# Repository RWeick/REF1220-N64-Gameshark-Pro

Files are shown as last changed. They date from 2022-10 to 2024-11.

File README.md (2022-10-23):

# REF1220-N64-Gameshark-Pro
An optimized PCB for the N64 Gameshark Pro as well as the full schematic. This is the second revision of the N64 Gameshark which was intended to support a smart card method of updating codes and adding features. The Gameshark Pro bin file should be programmed with the low bytes to the bottom SST and the high bytes to the top SST. It's worth noting that no smart cards were ever released for use with this Gameshark.

PCB Thickness: 1.2 mm

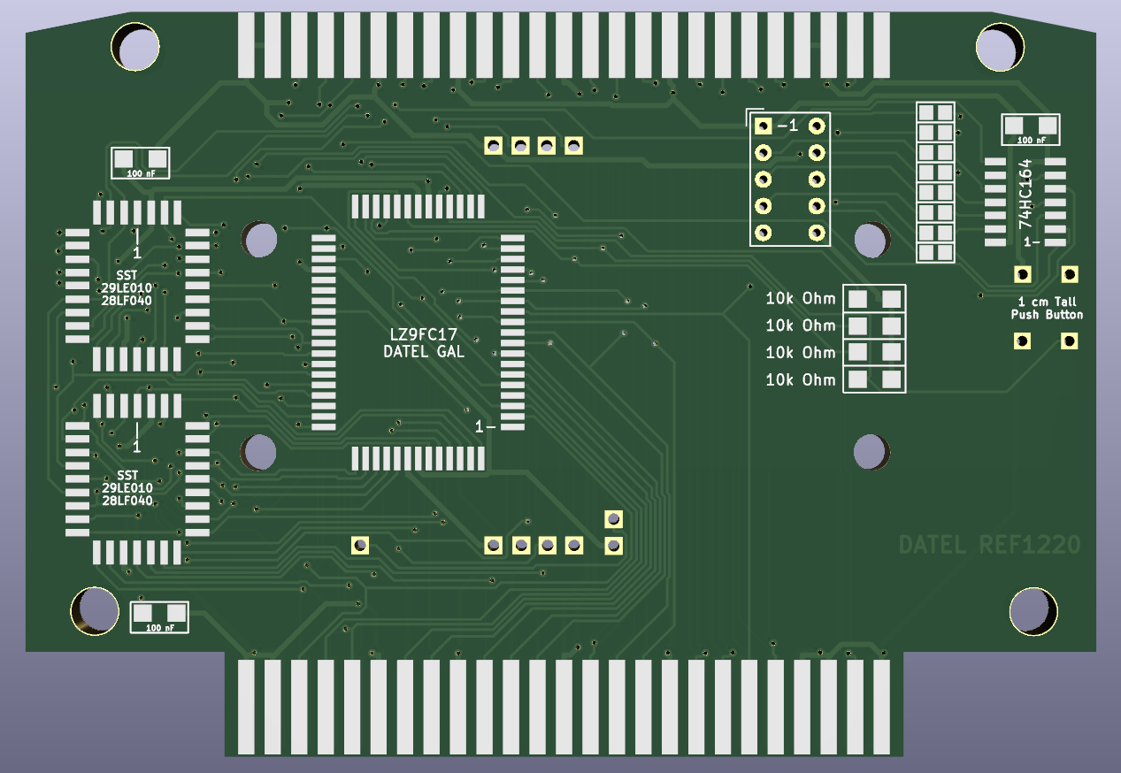
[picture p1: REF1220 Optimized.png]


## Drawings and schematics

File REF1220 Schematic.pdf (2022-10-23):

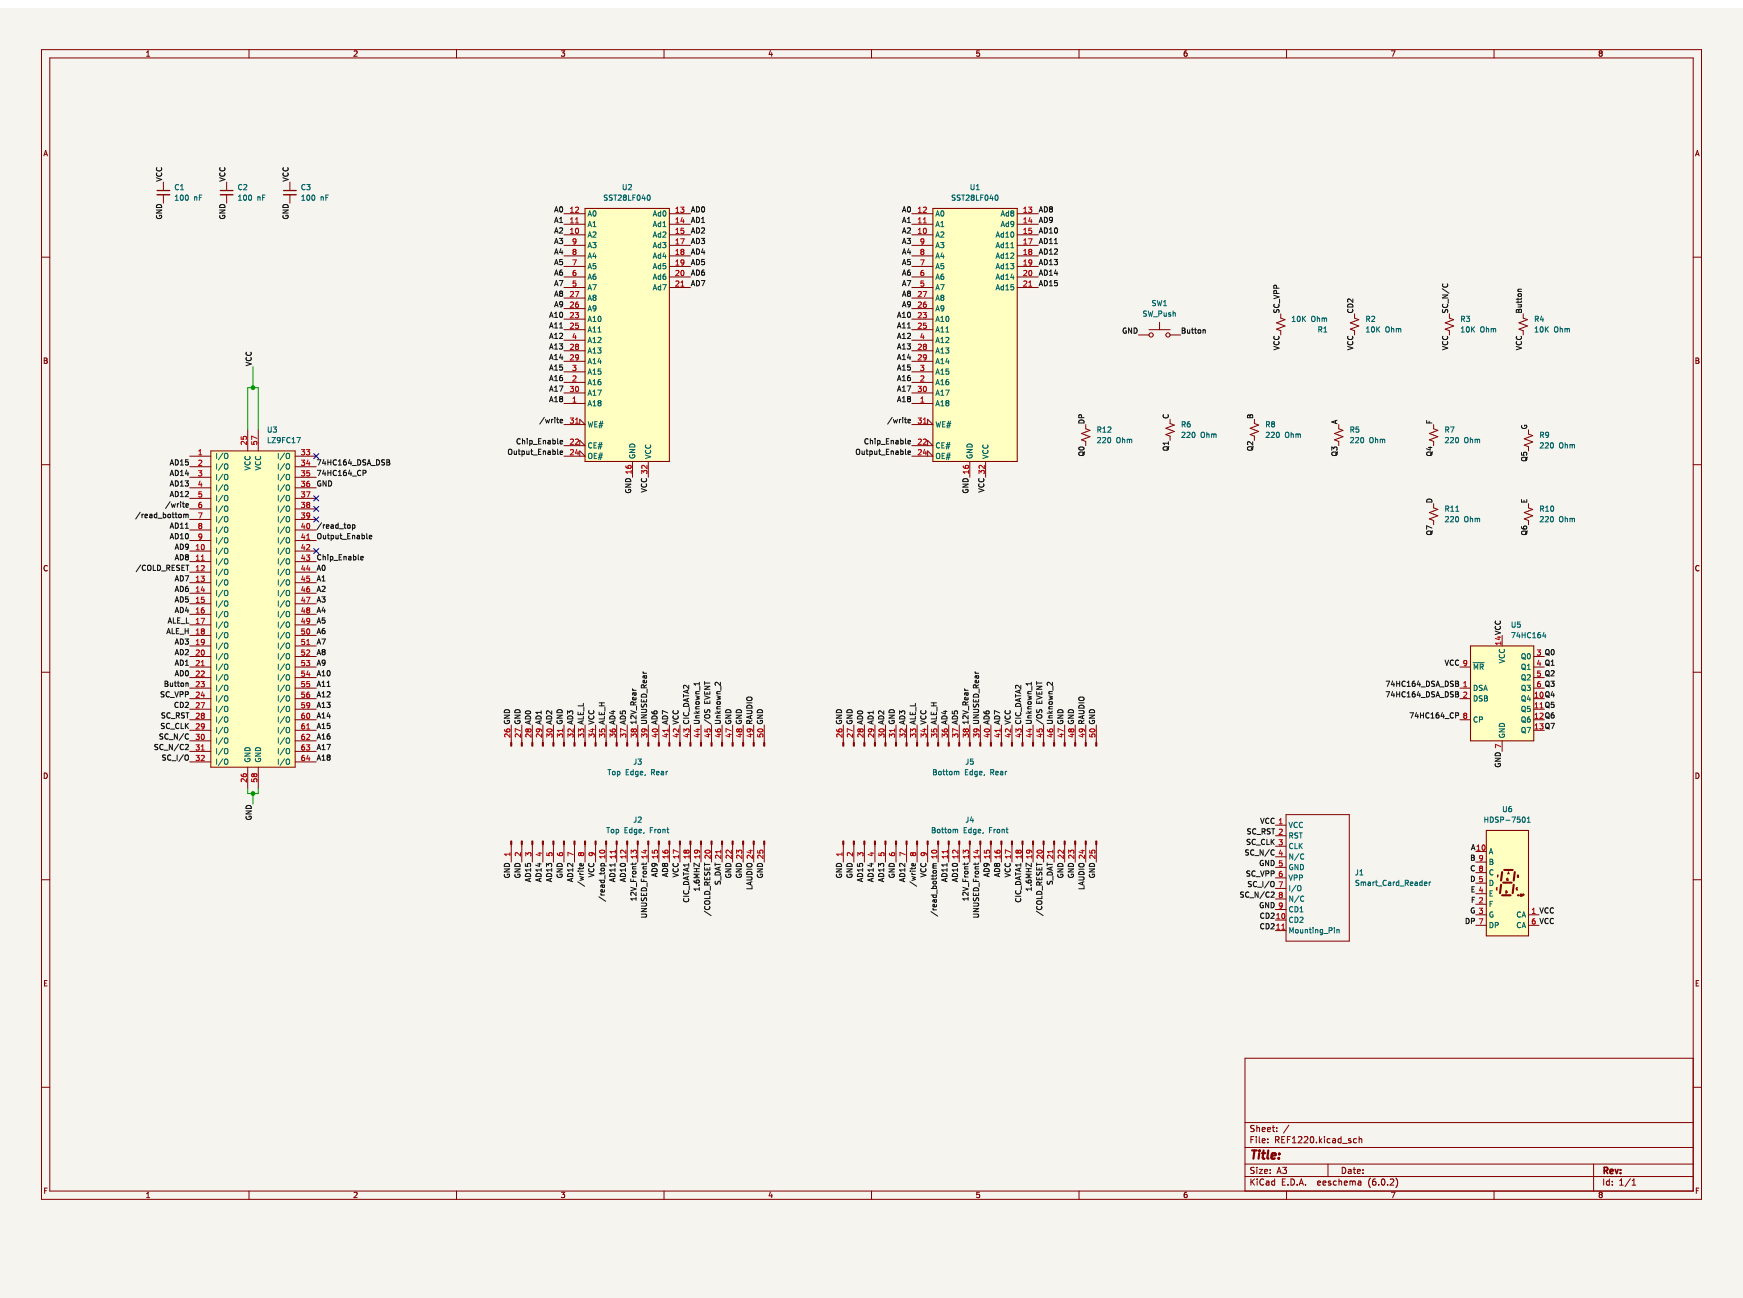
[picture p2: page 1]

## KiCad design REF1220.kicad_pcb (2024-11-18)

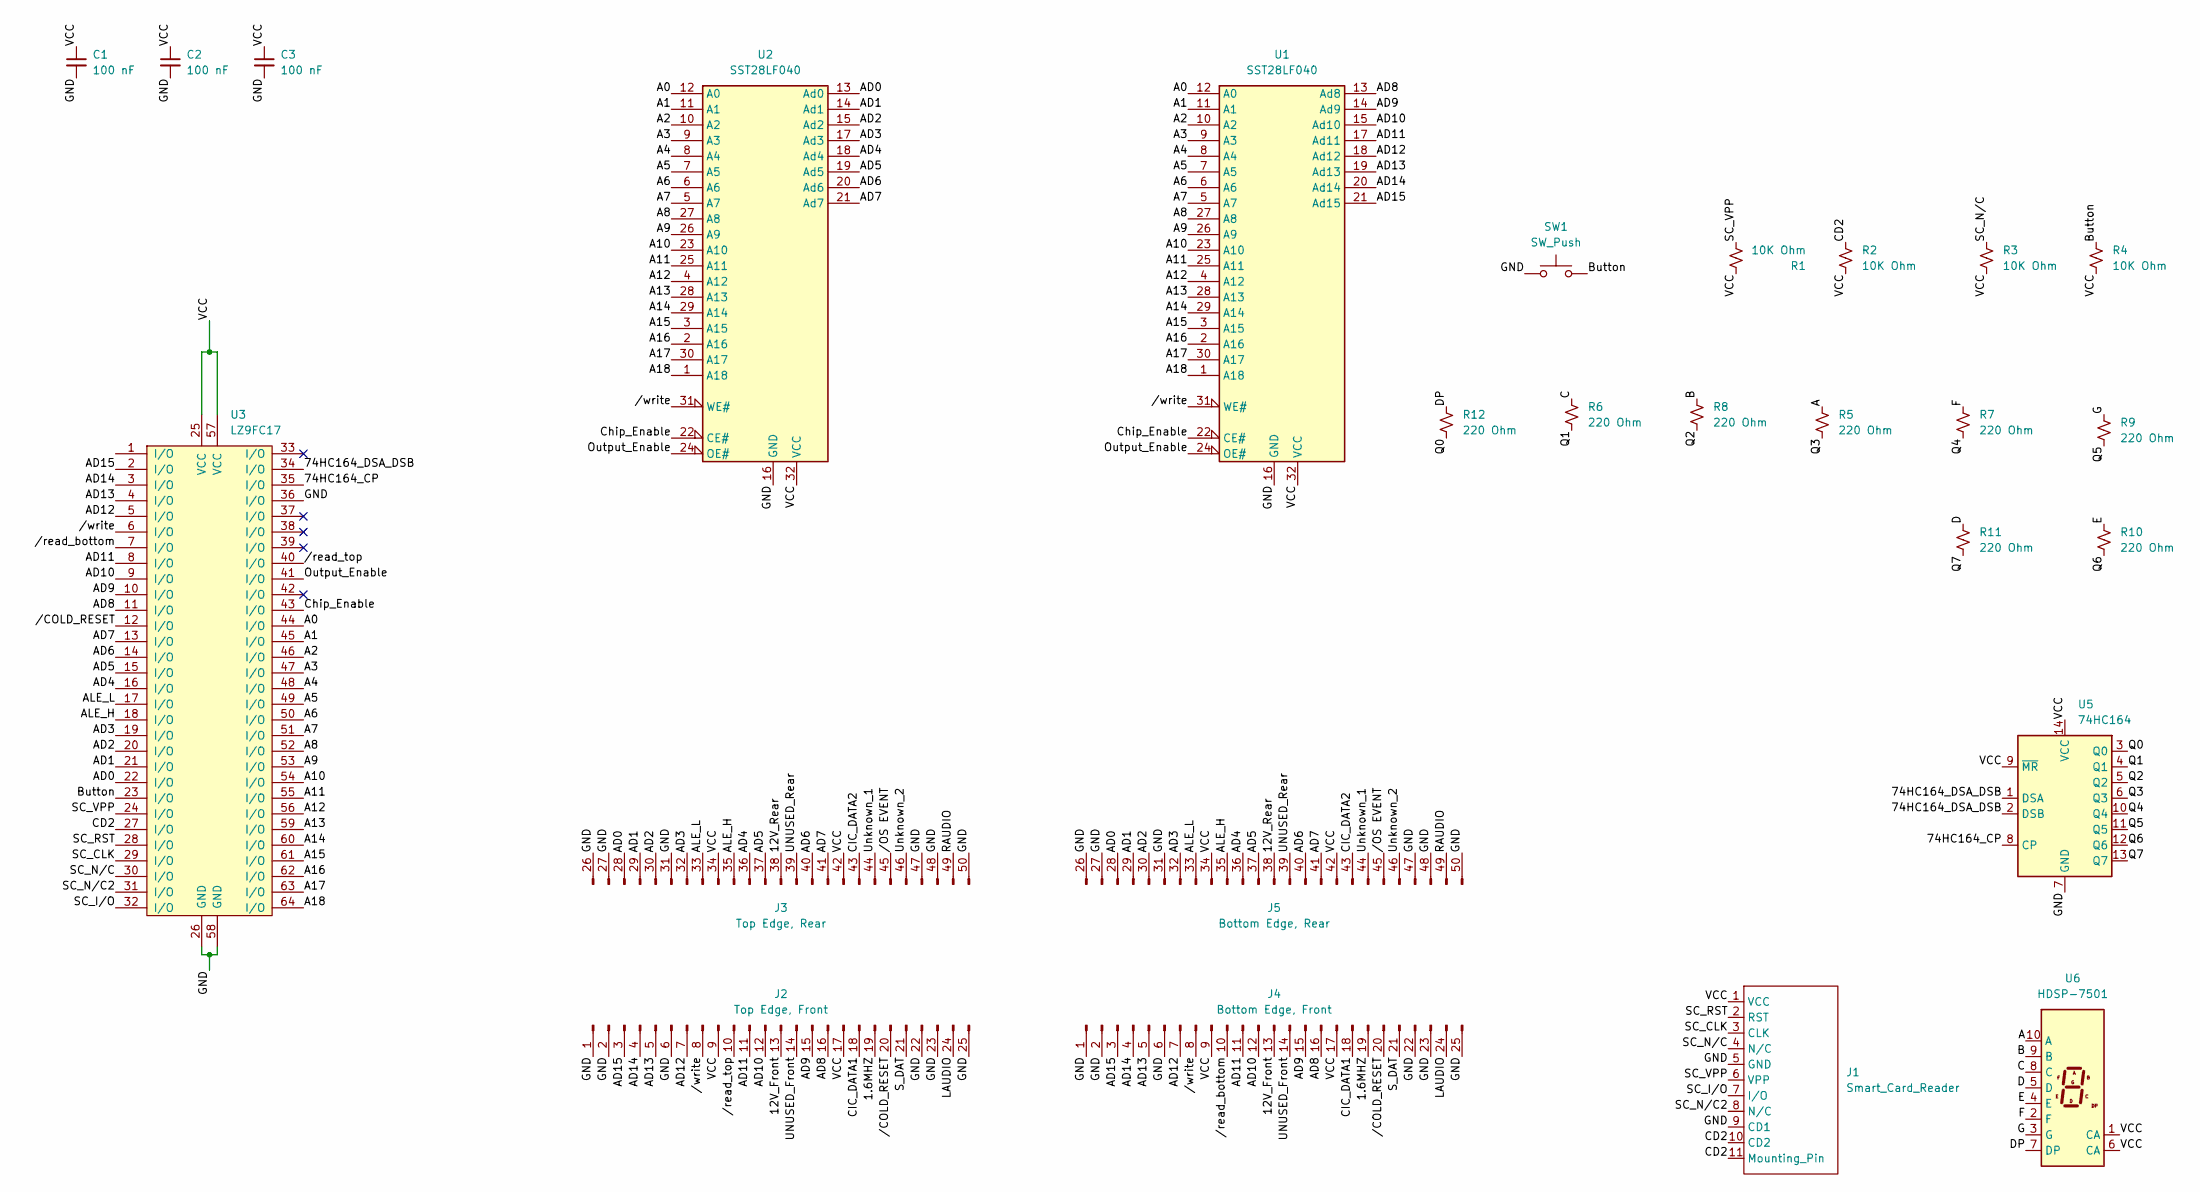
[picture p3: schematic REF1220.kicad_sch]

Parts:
C1, C2, C3: 100 nF; 100 nF Cap
J1: Smart_Card_Reader; Smart Card
J2: Top Edge, Front; Cart Edge Connector
J3: Top Edge, Rear; Cart Edge Connector Back
J4: Bottom Edge, Front; Cart Edge Connector
J5: Bottom Edge, Rear; Cart Edge Connector Back
R1, R2, R3, R4: 10K Ohm; 10k Ohm Resistor
R5, R6, R7, R8, R9, R10, R11, R12: 220 Ohm; 220 Ohm Resistor
SW1: SW_Push; 1mm Push Button
U1, U2: SST28LF040; PLCC32
U3: LZ9FC17; LZ9FC17 GAL
U5: 74HC164
U6: HDSP-7501; HDSP-7401

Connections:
/1.6MHZ: J2.19, J4.19
/12V_Front: J2.13, J4.13
/12V_Rear: J3.38 (Pin_13), J5.38 (Pin_13)
/74HC164_CP: U3.35 (I/O), U5.8 (CP)
/74HC164_DSA_DSB: U3.34 (I/O), U5.1 (DSA), U5.2 (DSB)
/A: R5.1, U6.10 (A)
/A0: U1.12 (A0), U2.12 (A0), U3.44 (I/O)
/A1: U1.11 (A1), U2.11 (A1), U3.45 (I/O)
/A2: U1.10 (A2), U2.10 (A2), U3.46 (I/O)
/A3: U1.9 (A3), U2.9 (A3), U3.47 (I/O)
/A4: U1.8 (A4), U2.8 (A4), U3.48 (I/O)
/A5: U1.7 (A5), U2.7 (A5), U3.49 (I/O)
/A6: U1.6 (A6), U2.6 (A6), U3.50 (I/O)
/A7: U1.5 (A7), U2.5 (A7), U3.51 (I/O)
/A8: U1.27 (A8), U2.27 (A8), U3.52 (I/O)
/A9: U1.26 (A9), U2.26 (A9), U3.53 (I/O)
/A10: U1.23 (A10), U2.23 (A10), U3.54 (I/O)
/A11: U1.25 (A11), U2.25 (A11), U3.55 (I/O)
/A12: U1.4 (A12), U2.4 (A12), U3.56 (I/O)
/A13: U1.28 (A13), U2.28 (A13), U3.59 (I/O)
/A14: U1.29 (A14), U2.29 (A14), U3.60 (I/O)
/A15: U1.3 (A15), U2.3 (A15), U3.61 (I/O)
/A16: U1.2 (A16), U2.2 (A16), U3.62 (I/O)
/A17: U1.30 (A17), U2.30 (A17), U3.63 (I/O)
/A18: U1.1 (A18), U2.1 (A18), U3.64 (I/O)
/AD0: J3.28 (Pin_3), J5.28 (Pin_23), U2.13 (Ad0), U3.22 (I/O)
/AD1: J3.29 (Pin_4), J5.29 (Pin_22), U2.14 (Ad1), U3.21 (I/O)
/AD2: J3.30 (Pin_5), J5.30 (Pin_21), U2.15 (Ad2), U3.20 (I/O)
/AD3: J3.32 (Pin_7), J5.32 (Pin_19), U2.17 (Ad3), U3.19 (I/O)
/AD4: J3.36 (Pin_11), J5.36 (Pin_15), U2.18 (Ad4), U3.16 (I/O)
/AD5: J3.37 (Pin_12), J5.37 (Pin_14), U2.19 (Ad5), U3.15 (I/O)
/AD6: J3.40 (Pin_15), J5.40 (Pin_11), U2.20 (Ad6), U3.14 (I/O)
/AD7: J3.41 (Pin_16), J5.41 (Pin_10), U2.21 (Ad7), U3.13 (I/O)
/AD8: J2.16, J4.16, U1.13 (Ad8), U3.11 (I/O)
/AD9: J2.15, J4.15, U1.14 (Ad9), U3.10 (I/O)
/AD10: J2.12, J4.12, U1.15 (Ad10), U3.9 (I/O)
/AD11: J2.11, J4.11, U1.17 (Ad11), U3.8 (I/O)
/AD12: J2.7, J4.7, U1.18 (Ad12), U3.5 (I/O)
/AD13: J2.5, J4.5, U1.19 (Ad13), U3.4 (I/O)
/AD14: J2.4, J4.4, U1.20 (Ad14), U3.3 (I/O)
/AD15: J2.3, J4.3, U1.21 (Ad15), U3.2 (I/O)
/ALE_H: J3.35 (Pin_10), J5.35 (Pin_16), U3.18 (I/O)
/ALE_L: J3.33 (Pin_8), J5.33 (Pin_18), U3.17 (I/O)
/B: R8.1, U6.9 (B)
/Button: R4.1, SW1.2, U3.23 (I/O)
/C: R6.1, U6.8 (C)
/CD2: J1.10 (CD2), J1.11 (Mounting_Pin), R2.1, U3.27 (I/O)
/CIC_DATA1: J2.18, J4.18
/CIC_DATA2: J3.43 (Pin_18), J5.43 (Pin_8)
/Chip_Enable: U1.22 (CE#), U2.22 (CE#), U3.43 (I/O)
/D: R11.1, U6.5 (D)
/DP: R12.1, U6.7 (DP)
/E: R10.1, U6.4 (E)
/F: R7.1, U6.2 (F)
/G: R9.1, U6.3 (G)
/GND: C1.2, C2.2, C3.2, J1.5 (GND), J1.9 (CD1), J2.1, J2.2, J2.6, J2.22, J2.23, J2.25, J3.26 (Pin_1), J3.27 (Pin_2), J3.31 (Pin_6), J3.47 (Pin_22), J3.48 (Pin_23), J3.50 (Pin_25), J4.1, J4.2, J4.6, J4.22, J4.23, J4.25, J5.26 (Pin_25), J5.27 (Pin_24), J5.31 (Pin_20), J5.47 (Pin_4), J5.48 (Pin_3), J5.50 (Pin_1), SW1.1, U1.16 (GND), U2.16 (GND), U3.26 (GND), U3.36 (I/O), U3.58 (GND), U5.7 (GND)
/LAUDIO: J2.24, J4.24
/Output_Enable: U1.24 (OE#), U2.24 (OE#), U3.41 (I/O)
/Q0: R12.2, U5.3 (Q0)
/Q1: R6.2, U5.4 (Q1)
/Q2: R8.2, U5.5 (Q2)
/Q3: R5.2, U5.6 (Q3)
/Q4: R7.2, U5.10 (Q4)
/Q5: R9.2, U5.11 (Q5)
/Q6: R10.2, U5.12 (Q6)
/Q7: R11.2, U5.13 (Q7)
/RAUDIO: J3.49 (Pin_24), J5.49 (Pin_2)
/SC_CLK: J1.3 (CLK), U3.29 (I/O)
/SC_I/O: J1.7 (I/O), U3.32 (I/O)
/SC_N/C: J1.4 (N/C), R3.1, U3.30 (I/O)
/SC_N/C2: J1.8 (N/C), U3.31 (I/O)
/SC_RST: J1.2 (RST), U3.28 (I/O)
/SC_VPP: J1.6 (VPP), R1.1, U3.24 (I/O)
/S_DAT: J2.21, J4.21
/UNUSED_Front: J2.14, J4.14
/UNUSED_Rear: J3.39 (Pin_14), J5.39 (Pin_12)
/Unknown_1: J3.44 (Pin_19), J5.44 (Pin_7)
/Unknown_2: J3.46 (Pin_21), J5.46 (Pin_5)
/VCC: C1.1, C2.1, C3.1, J1.1 (VCC), J2.9, J2.17, J3.34 (Pin_9), J3.42 (Pin_17), J4.9, J4.17, J5.34 (Pin_17), J5.42 (Pin_9), R1.2, R2.2, R3.2, R4.2, U1.32 (VCC), U2.32 (VCC), U3.25 (VCC), U3.57 (VCC), U5.9 (~MR), U5.14 (VCC), U6.1 (CA), U6.6 (CA)
//COLD_RESET: J2.20, J4.20, U3.12 (I/O)
//OS EVENT: J3.45 (Pin_20), J5.45 (Pin_6)
//read_bottom: J4.10, U3.7 (I/O)
//read_top: J2.10, U3.40 (I/O)
//write: J2.8, J4.8, U1.31 (WE#), U2.31 (WE#), U3.6 (I/O)

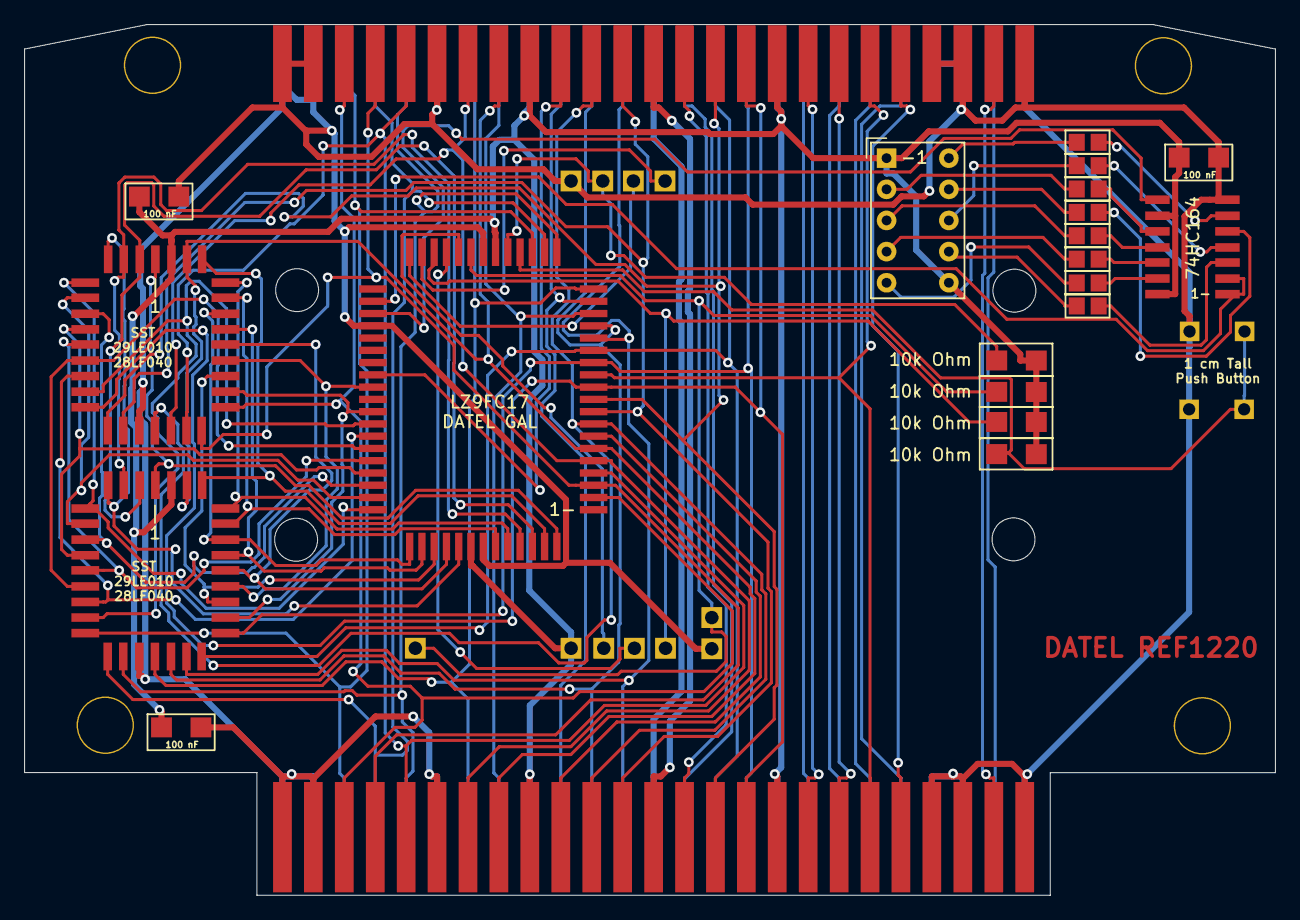
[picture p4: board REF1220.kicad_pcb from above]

Board: 2 copper layers, 102.0 x 71.0 mm, 34 parts (0 on the bottom side), 84 nets.

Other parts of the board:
Hole1, Hole2, Hole3, Hole4: N64-Hole
Hole5, Hole6, Hole7, Hole8: MountingHole_2.1mm
